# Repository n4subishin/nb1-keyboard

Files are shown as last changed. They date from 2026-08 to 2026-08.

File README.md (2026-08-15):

# Nb.1

*[日本語版はこちら / Japanese version](README.ja.md)*

A 12-position programmable macropad. Every position accepts **either a Cherry MX
compatible switch or a rotary encoder** — the two share a single footprint, so
you can build it as twelve keys, twelve knobs, or any mix in between. One
firmware build covers every variant.

| | |
|---|---|
| MCU | STM32F405RGT6 (Cortex-M4F, 168 MHz, 1 MB Flash, 192 KB RAM) |
| Matrix | 3 rows × 4 columns, COL2ROW |
| Encoders | Up to 12, wired directly to GPIO |
| Connection | USB Type-C, USB 2.0 Full Speed |
| Firmware | QMK Firmware (ChibiOS) |
| Configurator | Remap / VIA |

---

## Changing the keymap

No programming required — everything happens in the browser.

1. Open https://remap-keys.app/ in **Chrome or Edge**
   (Firefox and Safari do not implement WebHID and will not connect)
2. Choose **Customize your keyboard** and connect Nb.1
3. Drag and drop keycodes onto the positions you want to change
4. Press **flash**

Click a knob to set its clockwise and counter-clockwise actions separately.

Until Nb.1 is listed in the Remap catalog, load
[`Nb1_remap_definition.json`](Nb1_remap_definition.json) into Remap first.

---

## Building the firmware

You need a working QMK environment. See the
[QMK setup guide](https://docs.qmk.fm/newbs_getting_started) if you don't have one.

```sh
git clone https://github.com/qmk/qmk_firmware.git
cd qmk_firmware
qmk setup

# Drop this repository's keyboard directory into the QMK tree
cp -r /path/to/nb1-keyboard/keyboards/nb1 keyboards/

qmk compile -kb nb1 -km via
```

Two keymaps are provided. `default` is plain QMK; `via` adds Remap/VIA support
and is what ships on the board.

### Clock configuration

Y1 is a **16 MHz** crystal. QMK's `GENERIC_STM32_F405XG` board assumes 12 MHz,
so `board.h` and `mcuconf.h` override it:

```
PFD 2 MHz -> VCO 336 MHz -> SYSCLK 168 MHz, USB 48 MHz
```

**Deleting those two files breaks USB entirely** — the USB clock would land at
64 MHz instead of the required 48 MHz, and the core would run at 224 MHz, well
past its 168 MHz limit.

### EEPROM persistence

The STM32F405 has no real EEPROM, and QMK's flash emulation does not cover this
part by default, so it would silently fall back to a RAM-backed fake EEPROM and
lose every remap on unplug. `keymaps/via/rules.mk` selects the wear-leveling
driver explicitly to prevent that. Do not remove those lines.

---

## Flashing

Two ways into the bootloader:

**Keycode** — hold position 12 (bottom right) to reach layer 1, then press
position 1. That is `QK_BOOT` in the shipped keymap.

**BOOT0 button** — unplug USB, hold the BOOT0 button on the PCB, plug USB back
in. This works even when the firmware does not boot at all.

```sh
qmk flash -kb nb1 -km via
```

---

## Hardware

| | |
|---|---|
| PCB | 96.72 × 95.00 mm, 2 layer |
| Key pitch | 19.2 mm |
| Switches | Cherry MX compatible, Kailh hotswap sockets |
| Encoders | Alps EC12E2440301 (24 detent / 24 pulse, no push switch) |
| Crystal | 16 MHz, CL = 20 pF, HC-49/S |

Full details in [`docs/SPECIFICATION.md`](docs/SPECIFICATION.md).

### Known limitations

- **No SWD header.** Debugging requires soldering directly to MCU pins 46 and 49.
- **No reset button.** Can be retrofitted by adding a tactile switch in parallel
  with C8.
- **Matrix rows pass through the J16–J17 cable.** If that cable is disconnected,
  no key responds at all while the encoders keep working. This is the first
  thing to check when keys go dead.
- **The encoders have no push switch,** so a position fitted with an encoder
  responds to rotation only.

### JTAG pins

PA15 (JTDI), PB3 (JTDO) and PB4 (NJTRST) are used for the indicator LED and for
matrix row 3 / column 1. The board is SWD-only by design; a JTAG probe will not
work.

---

## License

Based on QMK Firmware, so this project is **GPL v2**. See [`LICENSE`](LICENSE).

USB VID `0x1209` is allocated by [pid.codes](https://pid.codes/) for open source
hardware. Projects using it must be released under a recognised open source
license, which this repository satisfies.

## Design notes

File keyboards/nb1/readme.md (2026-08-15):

# original_keyboard

A 12-position programmable input device built around an STM32F405RGT6.
Every position takes either a Cherry MX compatible switch (on a Kailh hotswap
socket) or a rotary encoder — the two share a single footprint, so the build
can be all keys, all encoders, or any mix. One firmware covers every variant.

* Keyboard maintainer: you
* Hardware supported: original_keyboard rev 1.0
* Hardware availability: self-made

## Layout

```
       col1   col2   col3   col4
 row1 [  1 ] [  2 ] [  3 ] [  4 ]
 row2 [  5 ] [  6 ] [  7 ] [  8 ]
 row3 [  9 ] [ 10 ] [ 11 ] [ 12 ]
```

Matrix position `[row, col]` and encoder index share the same physical spot:
encoder index = `row * 4 + col`.

## Building

```sh
qmk compile -kb original_keyboard -km default
```

## Flashing

```sh
qmk flash -kb original_keyboard -km default
```

Two ways to enter the bootloader:

* **Keycode** — hold position 9, press position 1 (`QK_BOOT` on the FN layer)
* **Hardware** — hold the BOOT0 button while plugging in USB

## Clock configuration

Y1 is a 16 MHz crystal (HUSG-16.000-20, CL = 20 pF). `board.h` and `mcuconf.h`
override the generic F405 board defaults:

```
PFD 2 MHz -> VCO 336 MHz -> SYSCLK 168 MHz, USB 48 MHz
```

Check `platforms/chibios/boards/GENERIC_STM32_F405XG/configs/` first — if the
defaults already match, delete both files.

## Notes

* PA15, PB3 and PB4 are JTAG pins at reset (JTDI / JTDO / NJTRST) and are used
  here for the indicator LED, matrix row 3 and matrix column 1. SWD-only debug
  is required; a JTAG probe will not work.
* The three matrix rows run through the J16 → cable → J17 jumper. If no key
  responds but the encoders do, check that cable first.

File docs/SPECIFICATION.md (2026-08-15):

# Nb.1 製品仕様書

Rev. 1.0 / 2026-08-06
KiCad 回路図 (`nb1.kicad_sch`) および基板 (`nb1.kicad_pcb`) より作成

---

## 1. 製品概要

12ポジションのプログラマブル入力デバイス。各ポジションは **Cherry MX 互換スイッチ**
または **ロータリーエンコーダ** のどちらかを選んで実装できる共用フットプリントを
採用しており、用途に応じて構成を変更できる。

USB Type-C 接続の有線デバイス。ファームウェアは QMK ベースで、
キーマップ・エンコーダ機能ともにユーザーが再定義可能。

| 項目 | 内容 |
|---|---|
| 型式 | Nb.1 |
| 入力ポジション数 | 12(3行 × 4列) |
| 各ポジションの選択肢 | Cherry MX 互換スイッチ / ロータリーエンコーダ |
| 接続 | USB 2.0 Full Speed (Type-C) |
| 電源 | USB バスパワー |
| ファームウェア | QMK Firmware (ChibiOS) |

---

## 2. 電気的仕様

### 2.1 マイクロコントローラ

| 項目 | 仕様 |
|---|---|
| 型番 | STM32F405RGT6 (U1) |
| コア | ARM Cortex-M4F @ 168 MHz |
| Flash / RAM | 1 MB / 192 KB |
| パッケージ | LQFP-64 |
| 動作電圧 | 3.3 V |

### 2.2 クロック

| 項目 | 仕様 |
|---|---|
| 発振子 (Y1) | HUSG-16.000-20、16 MHz、HC-49/S |
| 負荷容量 | CL = 20 pF(C9 / C10 = 30 pF) |
| 周波数許容差 | ±30 ppm |
| 周波数温度特性 | ±30 ppm |
| 直列抵抗 (R5) | 0 Ω |
| SYSCLK | 168 MHz(PLLM=8 / PLLN=168 / PLLP=2) |
| USB クロック | 48 MHz(PLLQ=7) |

### 2.3 電源

| 項目 | 仕様 |
|---|---|
| 入力 | USB VBUS 5 V |
| レギュレータ (U2) | M78AR033-0.5(R-78E3.3-0.5 互換) |
| 出力 | 3.3 V / 0.5 A |
| VDDA フィルタ | FB1(BLM18SP601SN1 相当)+ C12 (1 µF) / C13 (100 nF) |
| デカップリング | C3〜C7 |
| VCAP | C1 / C2(2.2 µF) |

### 2.4 USB

| 項目 | 仕様 |
|---|---|
| コネクタ (J1) | USB Type-C レセプタクル 16P(5077CR-16-SMC2-BK-TR) |
| 規格 | USB 2.0 Full Speed (12 Mbps) |
| D+ / D− | PA12 / PA11、直列 22 Ω (R3 / R4) |
| CC1 / CC2 | 5.1 kΩ プルダウン (R1 / R2) — UFP(デバイス)構成 |
| VID / PID | 0xFEED / 0x0001(出荷時、変更可) |

### 2.5 インジケータ LED

| 項目 | 仕様 |
|---|---|
| 素子 (D13) | 赤色 0603、Vf 1.8〜2.4 V、300 mcd @ 20 mA |
| 制御ピン | PA15 |
| 極性 | アノード → PA15、カソード → R6 → GND |
| 論理 | アクティブ HIGH |
| 電流制限 (R6) | 1 kΩ(実効電流 約 0.85〜1.45 mA) |

### 2.6 マトリクス

| 項目 | 仕様 |
|---|---|
| 構成 | 3行 × 4列 = 12キー |
| 行 (ROW) | PB1 / PB0 / PB3 |
| 列 (COL) | PB4 / PB5 / PB6 / PB7 |
| ダイオード | D1〜D12、SOD-123 |
| ダイオード方向 | COL2ROW(アノードが列側) |
| 行の経路 | MCU → J16 →(ケーブル)→ J17 → スイッチ |

### 2.7 ロータリーエンコーダ

12基すべてが MCU の GPIO に直結。マトリクスを介さない。

| ポジション | 行,列 | A相 | B相 | エンコーダ番号 |
|---|---|---|---|---|
| SW13 | 0,0 | PC9 | PC8 | 0 |
| SW16 | 0,1 | PA7 | PA6 | 1 |
| SW19 | 0,2 | PC13 | PC12 | 2 |
| SW22 | 0,3 | PC4 | PC5 | 3 |
| SW14 | 1,0 | PC1 | PC0 | 4 |
| SW17 | 1,1 | PC6 | PC7 | 5 |
| SW20 | 1,2 | PC15 | PC14 | 6 |
| SW23 | 1,3 | PA3 | PA2 | 7 |
| SW15 | 2,0 | PB8 | PB9 | 8 |
| SW18 | 2,1 | PC11 | PC10 | 9 |
| SW21 | 2,2 | PA5 | PA4 | 10 |
| SW24 | 2,3 | PA1 | PA0 | 11 |

共通端子 (C) は GND。内部プルアップを使用。

### 2.8 ブートローダ / デバッグ

| 項目 | 仕様 |
|---|---|
| BOOT0 | プッシュスイッチ (botton_1) で 3.3 V、R7 (10 kΩ) で GND |
| BOOT1 (PB2) | R8 (10 kΩ) で GND 固定 |
| NRST | C8 (100 nF) → GND |
| 書き込み | USB DFU(内蔵 ROM ブートローダ) |
| デバッグ | SWD (PA13 / PA14) — **基板上に端子未実装** |

---

## 3. 機構仕様

| 項目 | 仕様 |
|---|---|
| 基板外形 | 96.72 × 95.00 mm |
| 基板構成 | 両面 |
| キーピッチ | X 19.2 mm / Y 19.1 mm |
| 配列 | 3行 × 4列 グリッド |
| 取付穴 | 4箇所(MountingHole × 4) |

### 3.1 共用フットプリント寸法

各ポジションの詳細(座標はポジション中心を原点)。

**非メッキ穴(NPTH)**

| 位置 | 寸法 | 用途 |
|---|---|---|
| (0, 0) | φ4.00 mm | MX センターポスト |
| (±5.08, 0) | φ1.75 mm | MX 位置決めポスト |
| (−3.81, −2.54) | φ3.05 mm | MX スイッチピン逃げ |
| (2.54, −5.08) | φ3.05 mm | MX スイッチピン逃げ |
| (0.02, 5.00) | 長穴 11.0 × 2.6 mm | エンコーダ本体逃げ |

**裏面 SMD パッド(すべて B.Cu)**

| パッド | 位置 | サイズ | 用途 |
|---|---|---|---|
| 1 | (−7.08, −2.54) | 2.55 × 2.50 mm | Kailh ホットスワップソケット |
| 2 | (5.84, −5.08) | 2.55 × 2.50 mm | Kailh ホットスワップソケット |
| A | (−2.56, 2.95) | 1.10 × 1.10 mm | エンコーダ A相 |
| C | (2.54, 2.95) | 1.10 × 1.10 mm | エンコーダ 共通 |
| B | (−0.01, 7.05) | 1.10 × 1.10 mm | エンコーダ B相 |

### 3.2 ★ 未確定事項:エンコーダの適合

**エンコーダの型番が未確定です。発注・実装の前に必ず照合してください。**

判明している事実:

- A / B / C はすべて **1.1 mm 角の SMD パッド**(基板裏面 B.Cu)
- A-C 間 5.10 mm、B は A-C ラインから 4.10 mm オフセット、B は中央 (x≈0)
- 本体逃げは 11.0 × 2.6 mm の長穴
- スルーホール型の EC11 / EC12E とは**適合しません**

MX スイッチのボディ(14 × 14 mm、中心から ±7 mm)は A / B / C パッドの
位置と重なるため、**同一ポジションに MX スイッチとエンコーダを
同時実装することはできません。** 各ポジションはどちらか一方を選択します。

---

## 4. 構成の自由度

同一のファームウェアで、以下のいずれの構成にも対応します。
未実装のポジションは自動的に無効になります(エンコーダピンは内部プルアップ
により安定、マトリクス位置は反応しない)。

| 構成例 | MX スイッチ | エンコーダ | 用途 |
|---|---|---|---|
| フルキー | 12 | 0 | マクロパッド |
| フルエンコーダ | 0 | 12 | ミキサー / コントロールサーフェス |
| ハイブリッド A | 8 | 4 | 汎用(上段エンコーダ) |
| ハイブリッド B | 6 | 6 | DAW / 動画編集 |

---

## 5. 既知の制限事項

| # | 内容 | 影響 | 対策 |
|---|---|---|---|
| 1 | SWD 端子が未実装 | デバッガ接続不可 | MCU ピン 46 / 49 に直接配線 |
| 2 | リセットボタンなし | DFU 進入に USB 抜き差しが必要 | C8 に並列でタクトスイッチを追加 |
| 3 | 行配線が J16-J17 ケーブル経由 | ケーブル断でキー全滅 | 次回改版で基板上直結 |
| 4 | PA9 / PA10 が未接続 | ROM ブートローダの誤検出可能性 | 10 kΩ プルダウン追加 |
| 5 | フットプリントに MP パッドなし | KiCad DRC エラー | 次回改版で整合 |
| 6 | ネットラベルの番号ずれ | 可読性のみ(電気的問題なし) | 次回改版でリネーム |
| 7 | エンコーダ型番未確定 | 実装可否が未検証 | 3.2 節参照 |

### 5.1 JTAG ピンの制約

以下の3ピンは STM32F4 のリセット直後に JTAG 機能に割り当てられます。

| ピン | JTAG 機能 | 本製品での用途 |
|---|---|---|
| PA15 | JTDI | インジケータ LED |
| PB3 | JTDO | 行 IN_3 |
| PB4 | NJTRST | 列 OUT_1 |

SWD (PA13 / PA14) のみで運用するため動作に支障はありませんが、
**JTAG デバッガは使用できません。**

### 5.2 バックアップドメインピン

PC13 / PC14 / PC15 は出力駆動能力が 3 mA / 2 MHz に制限されます。
本製品ではエンコーダ入力にのみ使用するため影響ありません。

---

## 6. 未使用リソース

将来の拡張に利用可能な GPIO:

| ピン | 代表的な代替機能 | 想定用途 |
|---|---|---|
| PB10 / PB11 | I2C2_SCL / SDA | OLED ディスプレイ |
| PA8 | TIM1_CH1 | WS2812 RGB |
| PA9 / PA10 | USART1_TX / RX | シリアル、ブートローダ救済 |
| PC2 / PC3 | ADC | アナログ入力 |
| PB12〜PB15 | SPI2 | 外部メモリ等 |
| PD2 | — | 汎用 |

Flash 使用量は QMK 標準構成で 1 MB 中の一部のみ。RAM 192 KB。
機能拡張の余地は十分にあります。

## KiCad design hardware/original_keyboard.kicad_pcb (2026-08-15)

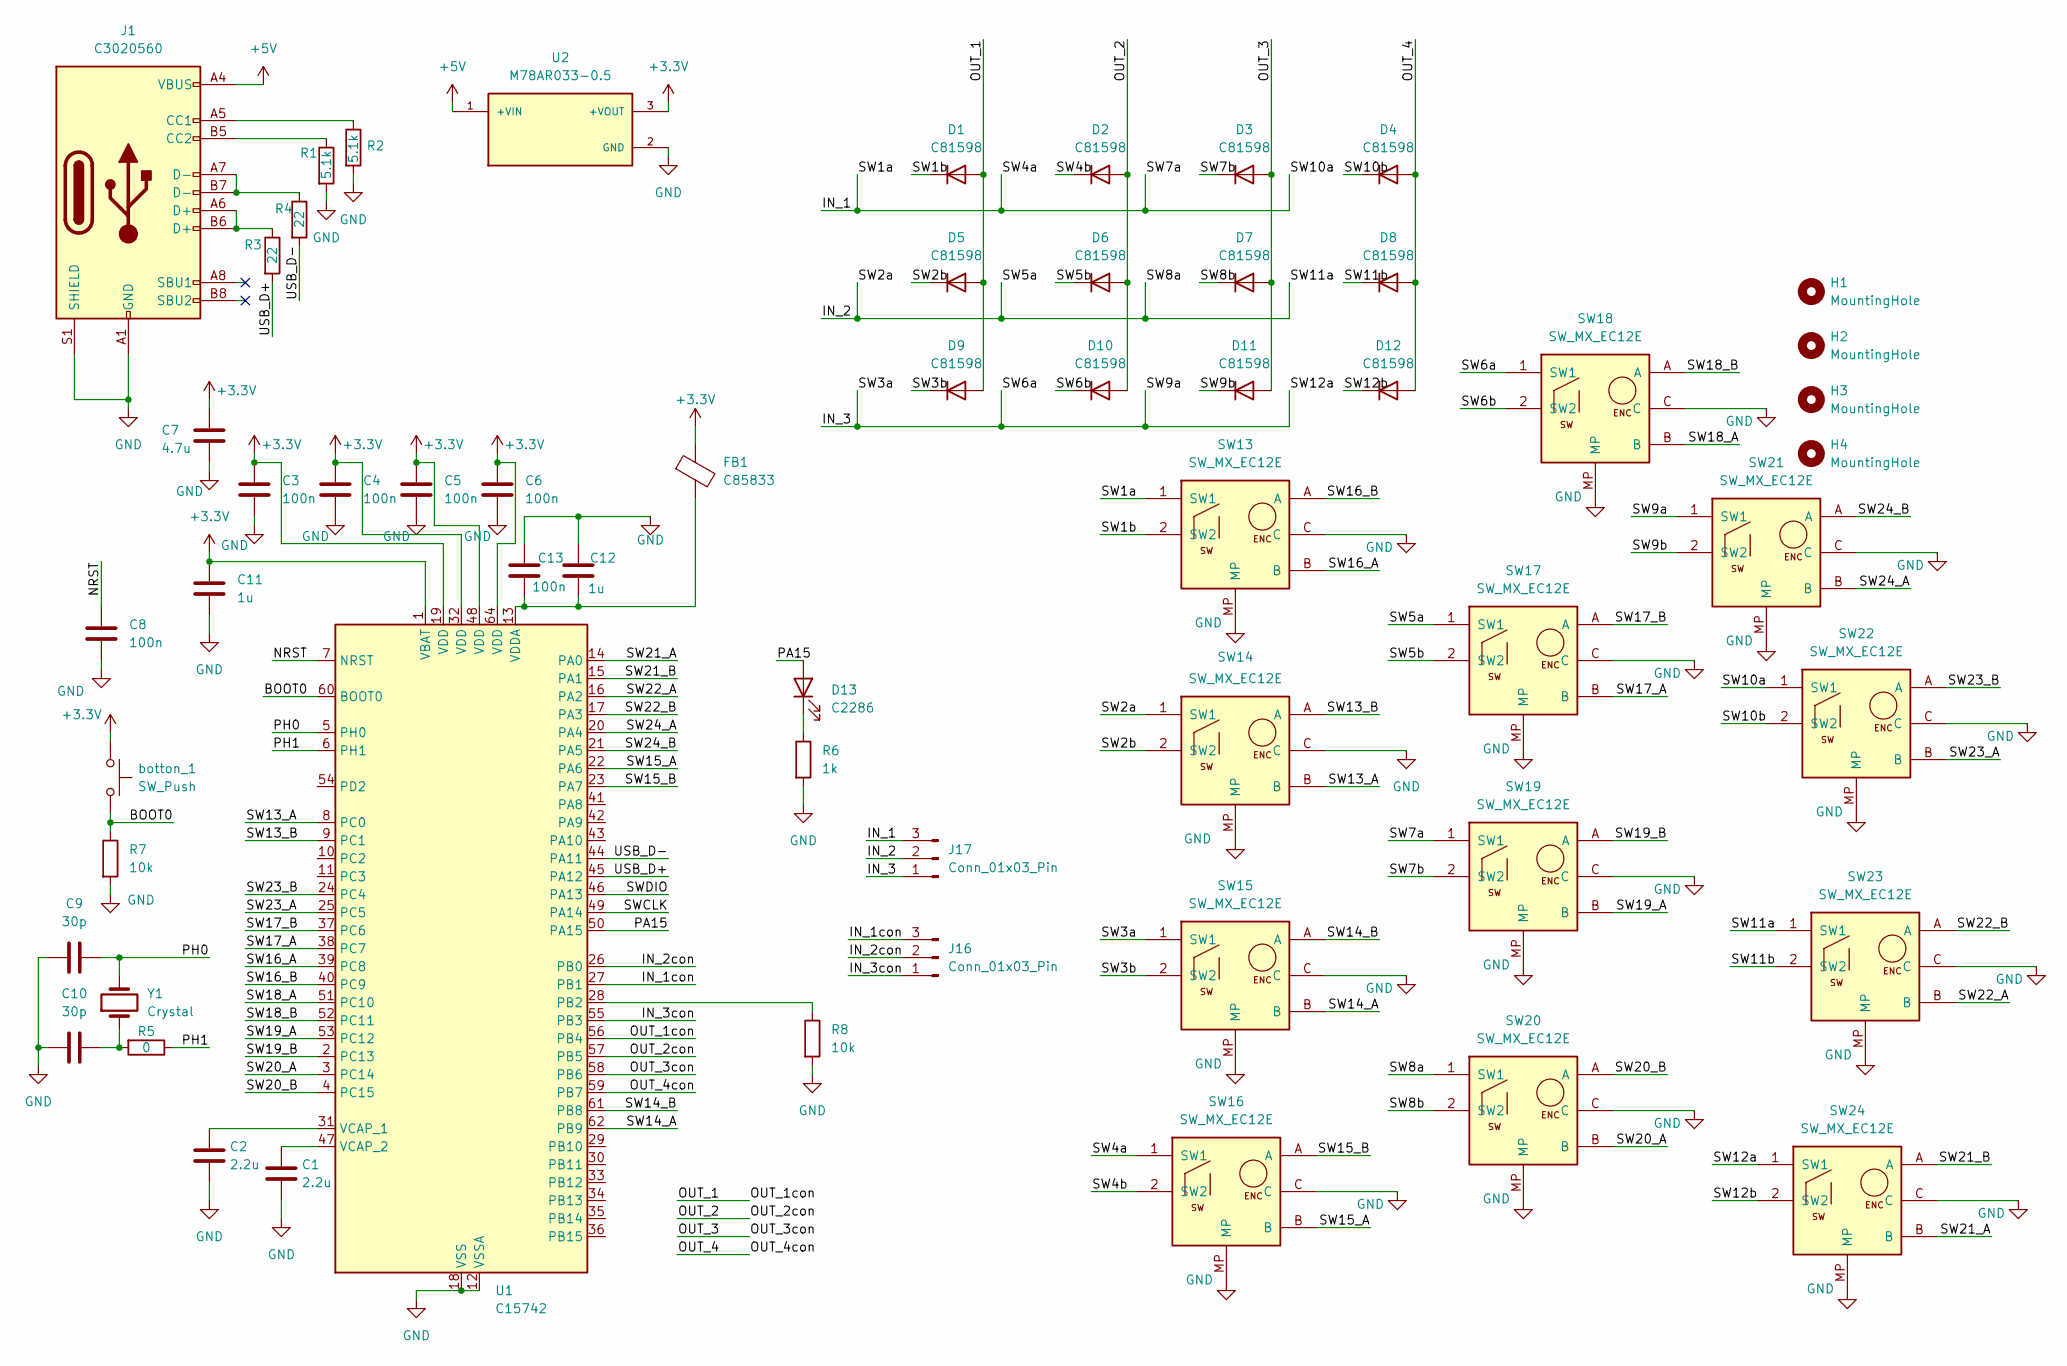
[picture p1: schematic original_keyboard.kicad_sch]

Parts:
C1, C2: 2.2u; C_0603_1608Metric
C3, C4, C5, C6, C8, C13: 100n; C_0603_1608Metric
C7: 4.7u; C_0603_1608Metric
C9, C10: 30p; C_0603_1608Metric
C11, C12: 1u; C_0603_1608Metric
D1, D2, D3, D4, D5, D6, D7, D8, D9, D10, D11, D12: C81598; D_SOD-123
D13: C2286; LED_0603_1608Metric
FB1: C85833; C_0603_1608Metric
H1, H2, H3, H4: MountingHole; MountingHole_3.2mm_M3
J1: C3020560; USB_C_Receptacle_GCT_USB4105-xx-A_16P_TopMnt_Horizontal
J16, J17: Conn_01x03_Pin; PinHeader_1x03_P2.54mm_Vertical
R1, R2: 5.1k; R_0603_1608Metric
R3, R4: 22; R_0603_1608Metric
R5: 0; R_0603_1608Metric
R6: 1k; R_0603_1608Metric
R7, R8: 10k; R_0603_1608Metric
SW13, SW14, SW15, SW16, SW17, SW18, SW19, SW20, SW21, SW22, SW23, SW24: SW_MX_EC12E; original1
U1: C15742; LQFP-64_10x10mm_P0.5mm
U2: M78AR033-0.5; PARTREV 4
Y1: Crystal; Crystal_HC49-U_Vertical
botton_1: SW_Push; SW_PUSH_6mm

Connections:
+3.3V: C3.1, C4.1, C5.1, C6.1, C7.1, C11.1, FB1.1, U1.1 (VBAT), U1.19 (VDD), U1.32 (VDD), U1.48 (VDD), U1.64 (VDD), U2.3 (+VOUT), botton_1.1
+5V: J1.A4 (VBUS), J1.A9 (VBUS), J1.B4 (VBUS), J1.B9 (VBUS), U2.1 (+VIN)
/BOOT0: R7.1, U1.60 (BOOT0), botton_1.2
/IN_1: J17.3, SW13.1 (SW1), SW16.1 (SW1), SW19.1 (SW1), SW22.1 (SW1)
/IN_1con: J16.3, U1.27 (PB1)
/IN_2: J17.2, SW14.1 (SW1), SW17.1 (SW1), SW20.1 (SW1), SW23.1 (SW1)
/IN_2con: J16.2, U1.26 (PB0)
/IN_3: J17.1, SW15.1 (SW1), SW18.1 (SW1), SW21.1 (SW1), SW24.1 (SW1)
/IN_3con: J16.1, U1.55 (PB3)
/NRST: C8.1, U1.7 (NRST)
/OUT_1: D1.2 (A), D5.2 (A), D9.2 (A), U1.56 (PB4)
/OUT_2: D2.2 (A), D6.2 (A), D10.2 (A), U1.57 (PB5)
/OUT_3: D3.2 (A), D7.2 (A), D11.2 (A), U1.58 (PB6)
/OUT_4: D4.2 (A), D8.2 (A), D12.2 (A), U1.59 (PB7)
/PA15: D13.2 (A), U1.50 (PA15)
/PH0: C9.1, U1.5 (PH0), Y1.2
/PH1: R5.1, U1.6 (PH1)
/SW1b: D1.1 (K), SW13.2 (SW2)
/SW2b: D5.1 (K), SW14.2 (SW2)
/SW3b: D9.1 (K), SW15.2 (SW2)
/SW4b: D2.1 (K), SW16.2 (SW2)
/SW5b: D6.1 (K), SW17.2 (SW2)
/SW6b: D10.1 (K), SW18.2 (SW2)
/SW7b: D3.1 (K), SW19.2 (SW2)
/SW8b: D7.1 (K), SW20.2 (SW2)
/SW9b: D11.1 (K), SW21.2 (SW2)
/SW10b: D4.1 (K), SW22.2 (SW2)
/SW11b: D8.1 (K), SW23.2 (SW2)
/SW12b: D12.1 (K), SW24.2 (SW2)
/SW13_A: SW14.B, U1.8 (PC0)
/SW13_B: SW14.A, U1.9 (PC1)
/SW14_A: SW15.B, U1.62 (PB9)
/SW14_B: SW15.A, U1.61 (PB8)
/SW15_A: SW16.B, U1.22 (PA6)
/SW15_B: SW16.A, U1.23 (PA7)
/SW16_A: SW13.B, U1.39 (PC8)
/SW16_B: SW13.A, U1.40 (PC9)
/SW17_A: SW17.B, U1.38 (PC7)
/SW17_B: SW17.A, U1.37 (PC6)
/SW18_A: SW18.B, U1.51 (PC10)
/SW18_B: SW18.A, U1.52 (PC11)
/SW19_A: SW19.B, U1.53 (PC12)
/SW19_B: SW19.A, U1.2 (PC13)
/SW20_A: SW20.B, U1.3 (PC14)
/SW20_B: SW20.A, U1.4 (PC15)
/SW21_A: SW24.B, U1.14 (PA0)
/SW21_B: SW24.A, U1.15 (PA1)
/SW22_A: SW23.B, U1.16 (PA2)
/SW22_B: SW23.A, U1.17 (PA3)
/SW23_A: SW22.B, U1.25 (PC5)
/SW23_B: SW22.A, U1.24 (PC4)
/SW24_A: SW21.B, U1.20 (PA4)
/SW24_B: SW21.A, U1.21 (PA5)
/SWCLK: U1.49 (PA14)
/SWDIO: U1.46 (PA13)
/USB_D+: R3.2, U1.45 (PA12)
/USB_D-: R4.2, U1.44 (PA11)
GND: C1.2, C2.2, C3.2, C4.2, C5.2, C6.2, C7.2, C8.2, C9.2, C10.2, C11.2, C12.1, C13.1, J1.A1 (GND), J1.A12 (GND), J1.B1 (GND), J1.B12 (GND), J1.S1 (SHIELD), R1.2, R2.2, R6.2, R7.2, R8.2, SW13.C, SW13.MP, SW14.C, SW14.MP, SW15.C, SW15.MP, SW16.C, SW16.MP, SW17.C, SW17.MP, SW18.C, SW18.MP, SW19.C, SW19.MP, SW20.C, SW20.MP, SW21.C, SW21.MP, SW22.C, SW22.MP, SW23.C, SW23.MP, SW24.C, SW24.MP, U1.12 (VSSA), U1.18 (VSS), U1.63 (VSS), U2.2 (GND)
unnamed: C10.1, R5.2, Y1.1
unnamed: D13.1 (K), R6.1
unnamed: J1.A5 (CC1), R2.1
unnamed: J1.B5 (CC2), R1.1
unnamed: J1.A6 (D+), J1.B6 (D+), R3.1
unnamed: J1.A7 (D-), J1.B7 (D-), R4.1
unnamed: R8.1, U1.28 (PB2)
unnamed: C2.1, U1.31 (VCAP_1)
unnamed: C1.1, U1.47 (VCAP_2)
unnamed: C12.2, C13.2, FB1.2, U1.13 (VDDA)

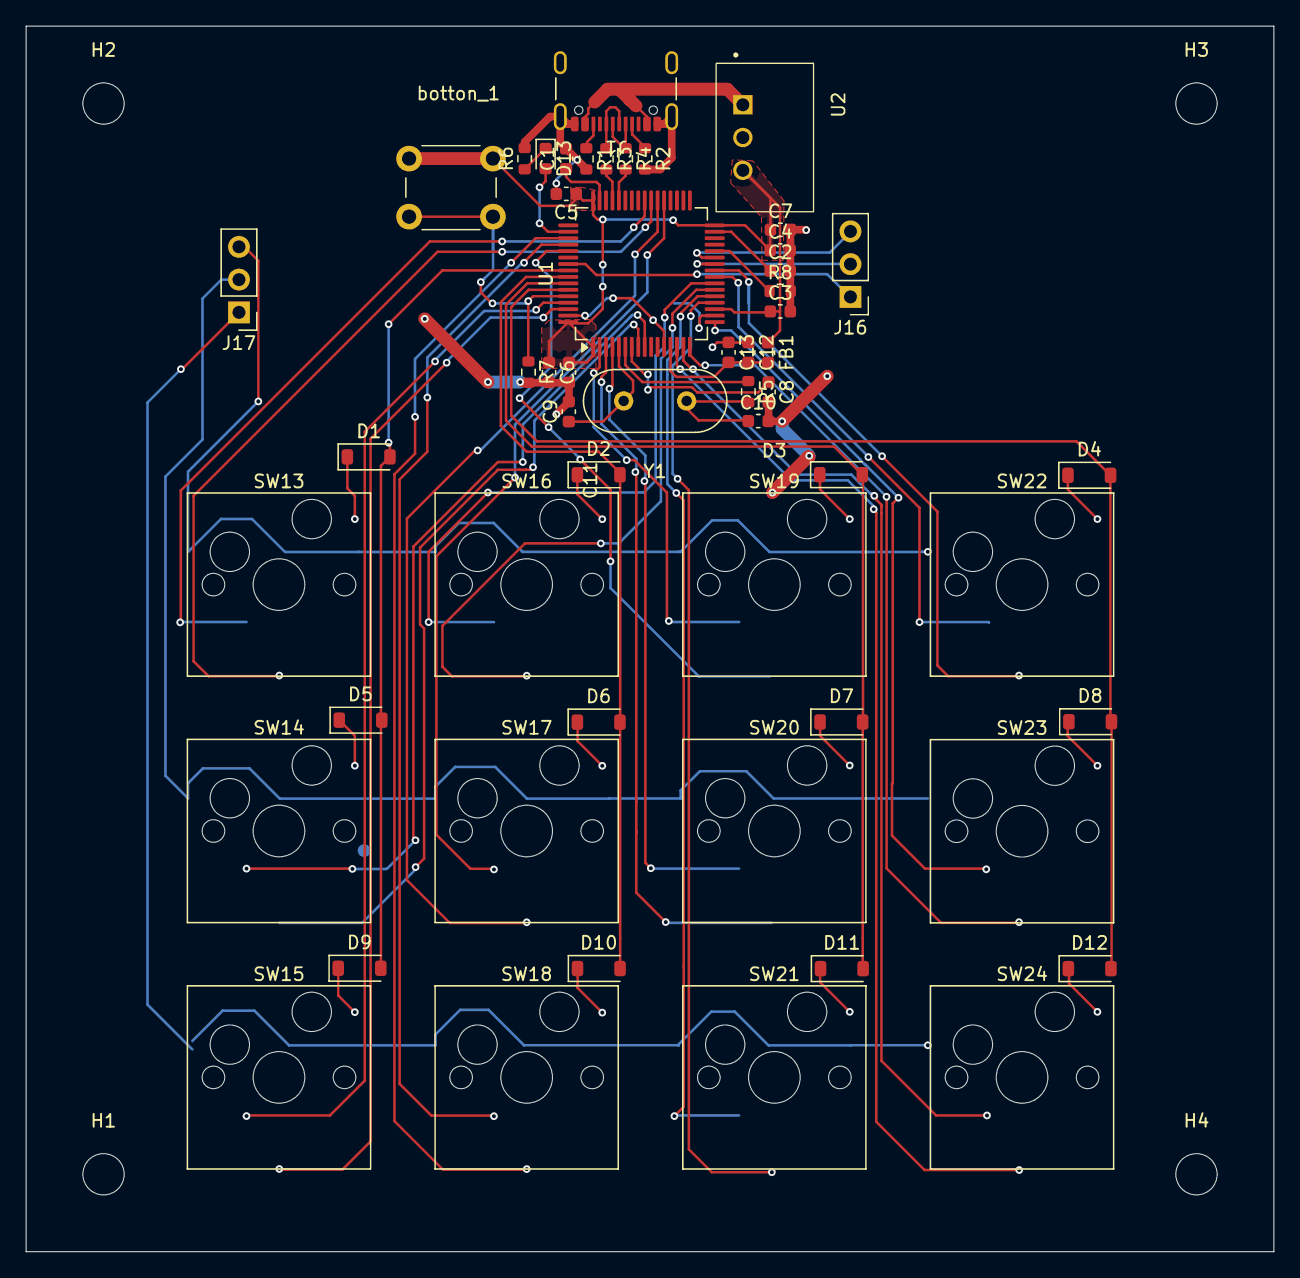
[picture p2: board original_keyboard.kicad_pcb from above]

Board: 2 copper layers, 96.7 x 95.0 mm, 58 parts (0 on the bottom side), 66 nets.

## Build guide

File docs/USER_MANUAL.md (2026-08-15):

# Nb.1 取扱説明書

Rev. 1.0 / 2026-08-06

---

## 1. はじめに

本製品は12ポジションのプログラマブル入力デバイスです。
各ポジションには **Cherry MX 互換スイッチ**または**ロータリーエンコーダ**の
どちらかが実装されています。

配列は3行 × 4列。左上を「1番」として、以下のように数えます。

```
       列1    列2    列3    列4
行1  [  1 ] [  2 ] [  3 ] [  4 ]
行2  [  5 ] [  6 ] [  7 ] [  8 ]
行3  [  9 ] [ 10 ] [ 11 ] [ 12 ]
```

---

## 2. 接続

USB Type-C ケーブルで PC に接続するだけです。ドライバのインストールは
不要で、標準的な USB キーボードとして認識されます。

Windows / macOS / Linux / ChromeOS に対応します。

**注意:** ケーブルは必ず**データ通信対応**のものを使ってください。
充電専用ケーブルでは認識されません。

---

## 3. 出荷時の割り当て

### 3.1 レイヤー構成

本製品には2つのレイヤーがあります。

| レイヤー | 名称 | 呼び出し方 |
|---|---|---|
| 0 | BASE | 通常状態 |
| 1 | FN | ポジション9を押している間 |

### 3.2 BASE レイヤー(通常時)

**押したとき**

| ポジション | 機能 |
|---|---|
| 1 | ミュート切り替え |
| 2 | 前のトラック |
| 3 | 再生 / 一時停止 |
| 4 | 次のトラック |
| 5 | テンキー 7 |
| 6 | テンキー 8 |
| 7 | テンキー 9 |
| 8 | ÷ |
| 9 | **FN レイヤー(押している間)** |
| 10 | テンキー 0 |
| 11 | . |
| 12 | Enter |

**回したとき(エンコーダ実装ポジション)**

| ポジション | 左回り | 右回り |
|---|---|---|
| 1 | 音量ダウン | 音量アップ |
| 2 | 前のトラック | 次のトラック |
| 3 | Page Down | Page Up |
| 4 | ← | → |
| 5 | ホイール下 | ホイール上 |
| 6 | ↑ | ↓ |
| 7 | マウス左 | マウス右 |
| 8 | Shift+Tab | Tab |
| 9 | − | = |
| 10 | [ | ] |
| 11 | , | . |
| 12 | 画面輝度ダウン | 画面輝度アップ |

### 3.3 FN レイヤー(ポジション9を押しながら)

| ポジション | 機能 |
|---|---|
| 1 | **書き込みモードに入る** |
| 2〜4 | F13 / F14 / F15 |
| 5〜8 | F16 / F17 / F18 / F19 |
| 10〜12 | F20 / F21 / F22 |

F13〜F22 は通常のキーボードには無いキーなので、
アプリのショートカット割り当てに便利です。

---

## 4. インジケータ LED

基板上の赤色 LED は、出荷時は **Num Lock 連動**です。
Num Lock がオンのときに点灯します。

レイヤー表示など、他の用途に変更することもできます(6章参照)。

---

## 5. 書き込みモード(ファームウェア更新)

ファームウェアを書き換えるには、書き込みモード(DFU モード)に入ります。
方法は2つあります。

### 方法1:キー操作(通常はこちら)

**ポジション9を押しながら、ポジション1を押す。**

即座に書き込みモードに入り、PC からは「STM32 BOOTLOADER」として
認識されます。キーボードとしては一時的に反応しなくなります。

### 方法2:BOOT0 ボタン(ファームが壊れたとき)

1. USB ケーブルを抜く
2. 基板上の **BOOT0 ボタンを押したまま**
3. USB ケーブルを挿す
4. ボタンを離す

ファームウェアが起動しない状態でも、この方法なら必ず書き込みモードに入れます。

### 書き込みコマンド

```bash
qmk flash -kb nb1 -km default
```

または

```bash
dfu-util -a 0 -d 0483:df11 -s 0x08000000:leave -D nb1_default.bin
```

書き込みが終わると自動的に再起動し、通常のキーボードに戻ります。

---

## 6. カスタマイズ

### 6.1 準備

QMK の開発環境を用意し、本製品のファイル一式を配置します。

```
qmk_firmware/keyboards/nb1/
├── keyboard.json
├── config.h
├── board.h
├── mcuconf.h
└── keymaps/default/
    ├── keymap.c
    └── rules.mk
```

ビルドは以下のコマンドです。

```bash
qmk compile -kb nb1 -km default
```

### 6.2 キーの割り当てを変える

`keymap.c` の `keymaps` 配列を編集します。左上から右下へ、
行ごとに並んでいます。

```c
[_BASE] = LAYOUT_3x4(
    KC_MUTE, KC_MPRV, KC_MPLY, KC_MNXT,   // ポジション 1〜4
    KC_P7,   KC_P8,   KC_P9,   KC_PSLS,   // ポジション 5〜8
    MO(_FN), KC_P0,   KC_PDOT, KC_PENT    // ポジション 9〜12
),
```

使えるキーコードの一覧は QMK 公式ドキュメントを参照してください。

### 6.3 エンコーダの割り当てを変える

`keymap.c` の `encoder_map` を編集します。
各行が `{ 左回り, 右回り }` です。

```c
{ KC_VOLD, KC_VOLU },  //  0  ポジション1
```

### 6.4 回転方向が逆のとき

`keyboard.json` の該当エンコーダの `pin_a` と `pin_b` を入れ替えます。

```json
{ "pin_a": "C8",  "pin_b": "C9"  }
```

### 6.5 1ノッチで2回動く / 半分しか動かないとき

`config.h` の以下の行のコメントを外して調整します。

```c
#define ENCODER_RESOLUTION 4
```

1ノッチで2回反応するなら値を大きく(4 → 8)、
半分しか反応しないなら小さく(4 → 2)します。

### 6.6 LED の動作を変える

`keymap.c` の以下の部分を書き換えます。

```c
bool led_update_user(led_t led_state) {
    writePin(INDICATOR_LED, led_state.num_lock);
    return false;
}
```

レイヤー表示にしたい場合は、`led_update_user` の中身を
`return false;` だけにして、`layer_state_set_user` を使います
(`keymap.c` にコメントで例を記載しています)。

---

## 7. トラブルシューティング

### PC に認識されない

まず**データ通信対応のケーブル**か確認してください。充電専用ケーブルが
原因のことが最も多いです。

それでも認識されない場合、BOOT0 ボタンを押しながら接続して
「STM32 BOOTLOADER」が見えるか確認します。

- **見える** → ファームウェアの問題。書き込み直してください
- **見えない** → ハードウェアの問題。組み立て手順書を参照してください

### キーが1つも反応しない(エンコーダは動く)

**J16 と J17 を繋ぐケーブルを確認してください。**
マトリクスの行3本すべてがこのケーブルを通っているため、
外れていると全キーが無反応になります。

エンコーダは MCU 直結なので、ケーブルが無くても動作します。
この症状が出たら、ほぼ確実にケーブルが原因です。

### キーの位置がずれている

J16-J17 のケーブルが逆向き(1-3、3-1)に繋がっています。
ケーブルを正しく繋ぎ直してください(1-1、2-2、3-3 のストレート)。

### 特定のキーだけ反応しない

そのポジションの以下を確認してください。

- Kailh ホットスワップソケットのはんだ付け
- スイッチのピンが曲がっていないか
- 対応するダイオードの向きとはんだ付け

### エンコーダが反応しない / 飛ぶ

- A / B / C パッドのはんだ付けを確認
- 反応が飛ぶ場合は `ENCODER_RESOLUTION` を調整(6.5節)
- 逆回転する場合は `pin_a` / `pin_b` を入れ替え(6.4節)

### 書き込み後に動かなくなった

BOOT0 ボタンを押しながら USB を挿せば、必ず書き込みモードに入れます。
正常に動いていたファームウェアを書き戻してください。

---

## 8. 取り扱い上の注意

- 動作温度範囲は 0〜50 ℃ を目安としてください
  (発振子の定格が −10〜60 ℃ です)
- 基板がむき出しの状態では、金属面の上に直接置かないでください
- USB ケーブルの抜き差しは、コネクタ部分を持って行ってください
- 分解・改造による故障は自己責任となります

---

## 9. 仕様

詳細は `SPECIFICATION.md` を参照してください。

| 項目 | 内容 |
|---|---|
| ポジション数 | 12(3 × 4) |
| 接続 | USB Type-C(USB 2.0 Full Speed) |
| 電源 | USB バスパワー |
| MCU | STM32F405RGT6 |
| 基板寸法 | 96.72 × 95.00 mm |
| キーピッチ | 19.2 mm |
| ファームウェア | QMK Firmware |

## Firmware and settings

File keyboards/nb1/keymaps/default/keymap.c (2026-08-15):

// Copyright 2026
// SPDX-License-Identifier: GPL-2.0-or-later

#include QMK_KEYBOARD_H

enum layers { _BASE = 0, _FN };

// ---------------------------------------------------------------------------
// Position numbering (matches the user manual)
//
//        col1   col2   col3   col4
//  row1 [  1 ] [  2 ] [  3 ] [  4 ]      SW13  SW16  SW19  SW22
//  row2 [  5 ] [  6 ] [  7 ] [  8 ]      SW14  SW17  SW20  SW23
//  row3 [  9 ] [ 10 ] [ 11 ] [ 12 ]      SW15  SW18  SW21  SW24
//
// Every position takes EITHER a Cherry MX switch (via a Kailh hotswap socket)
// OR a rotary encoder -- the two share one footprint and cannot coexist.
// This single firmware covers any mix: unpopulated encoders idle high on their
// internal pull-ups, and unpopulated matrix positions simply never trigger.
//
// NUM LOCK INDEPENDENCE
// KC_P0..KC_P9 and KC_PDOT change meaning when Num Lock is off (Home, arrows,
// Insert, Delete...). This board has no Num Lock key, so the user would have no
// way to fix that state. The digits below are the main-row keycodes KC_0..KC_9,
// which always send digits. Keypad OPERATORS (KC_PSLS, KC_PAST, KC_PMNS,
// KC_PPLS, KC_PENT) are not affected by Num Lock and are safe to use.
// ---------------------------------------------------------------------------

const uint16_t PROGMEM keymaps[][MATRIX_ROWS][MATRIX_COLS] = {
    // 7 8 9 Backspace / 4 5 6 Enter / 1 2 3 (tap 0, hold FN)
    [_BASE] = LAYOUT_3x4(
        KC_7,    KC_8,    KC_9,    KC_BSPC,
        KC_4,    KC_5,    KC_6,    KC_PENT,
        KC_1,    KC_2,    KC_3,    LT(_FN, KC_0)
    ),

    [_FN] = LAYOUT_3x4(
        KC_PSLS, KC_PAST, KC_PMNS, KC_DEL,
        KC_PPLS, KC_EQL,  KC_DOT,  KC_TAB,
        KC_COMM, KC_LPRN, KC_RPRN, _______
    ),
};

#ifdef ENCODER_MAP_ENABLE
// Same order as the "rotary" array in keyboard.json: { CCW, CW }
const uint16_t PROGMEM encoder_map[][NUM_ENCODERS][2] = {
    [_BASE] = {
        { KC_VOLD, KC_VOLU  },  //  0  position 1
        { KC_MPRV, KC_MNXT  },  //  1  position 2
        { KC_PGDN, KC_PGUP  },  //  2  position 3
        { KC_LEFT, KC_RGHT  },  //  3  position 4

        { MS_WHLD, MS_WHLU  },  //  4  position 5
        { KC_UP,   KC_DOWN  },  //  5  position 6
        { MS_LEFT, MS_RGHT  },  //  6  position 7
        { S(KC_TAB), KC_TAB },  //  7  position 8

        { KC_MINS, KC_EQL   },  //  8  position 9
        { KC_LBRC, KC_RBRC  },  //  9  position 10
        { KC_COMM, KC_DOT   },  // 10  position 11
        { KC_BRID, KC_BRIU  },  // 11  position 12
    },
    [_FN] = {
        { KC_VOLD, KC_VOLU },
        { KC_MPRV, KC_MNXT },
        { KC_HOME, KC_END  },
        { KC_LEFT, KC_RGHT },

        { MS_WHLD, MS_WHLU },
        { KC_UP,   KC_DOWN },
        { MS_LEFT, MS_RGHT },
        { S(KC_TAB), KC_TAB },

        { KC_MINS, KC_EQL  },
        { KC_LBRC, KC_RBRC },
        { KC_COMM, KC_DOT  },
        { KC_BRID, KC_BRIU },
    },
};
#endif

// ---------------------------------------------------------------------------
// Indicator LED on PA15
//
// Red 0603, anode to PA15, cathode through R6 (1k) to GND -> active HIGH.
// PA15 is JTDI at reset on STM32F4, so it has to be claimed as a plain GPIO
// output before use. Only SWD (PA13/PA14) is used for debug, so this is safe.
//
// Num Lock is meaningless on this board now, so the LED tracks the active
// layer instead: lit whenever the user is holding the FN layer.
// ---------------------------------------------------------------------------

#define INDICATOR_LED A15

void keyboard_post_init_user(void) {
    gpio_set_pin_output(INDICATOR_LED);
    gpio_write_pin_low(INDICATOR_LED);
}

layer_state_t layer_state_set_user(layer_state_t state) {
    gpio_write_pin(INDICATOR_LED, get_highest_layer(state) != _BASE);
    return state;
}

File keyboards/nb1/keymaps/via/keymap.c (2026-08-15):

// Copyright 2026
// SPDX-License-Identifier: GPL-2.0-or-later

#include QMK_KEYBOARD_H

// ---------------------------------------------------------------------------
// VIA / Remap keymap
//
// What is compiled here is only the FACTORY DEFAULT. Once the customer opens
// Remap and saves a change, their keymap lives in EEPROM and this file stops
// mattering. So the job here is a sensible out-of-the-box state, not a final
// design.
//
// Layer count must match DYNAMIC_KEYMAP_LAYER_COUNT (4) in config.h. Layers 2
// and 3 are left transparent for the customer to fill in.
//
//        col1   col2   col3   col4
//  row1 [  1 ] [  2 ] [  3 ] [  4 ]
//  row2 [  5 ] [  6 ] [  7 ] [  8 ]
//  row3 [  9 ] [ 10 ] [ 11 ] [ 12 ]
//
// Digits are the main-row KC_0..KC_9, never KC_P0..KC_P9: this board has no
// Num Lock key, so keypad digits would be stuck as Home/arrows/Insert whenever
// the host had Num Lock off, with no way for the customer to recover.
// ---------------------------------------------------------------------------

const uint16_t PROGMEM keymaps[][MATRIX_ROWS][MATRIX_COLS] = {
    [0] = LAYOUT_3x4(
        KC_7,    KC_8,    KC_9,    KC_BSPC,
        KC_4,    KC_5,    KC_6,    KC_PENT,
        KC_1,    KC_2,    KC_3,    LT(1, KC_0)
    ),

    [1] = LAYOUT_3x4(
        KC_PSLS, KC_PAST, KC_PMNS, KC_DEL,
        KC_PPLS, KC_EQL,  KC_DOT,  KC_TAB,
        KC_COMM, KC_LPRN, KC_RPRN, _______
    ),

    [2] = LAYOUT_3x4(
        _______, _______, _______, _______,
        _______, _______, _______, _______,
        _______, _______, _______, _______
    ),

    [3] = LAYOUT_3x4(
        _______, _______, _______, _______,
        _______, _______, _______, _______,
        _______, _______, _______, _______
    ),
};

#ifdef ENCODER_MAP_ENABLE
// Encoder index = row * 4 + col, matching the "rotary" array in keyboard.json.
// Each row is { counter-clockwise, clockwise }.
const uint16_t PROGMEM encoder_map[][NUM_ENCODERS][2] = {
    [0] = {
        { KC_VOLD, KC_VOLU  }, { KC_MPRV, KC_MNXT  },
        { KC_PGDN, KC_PGUP  }, { KC_LEFT, KC_RGHT  },
        { MS_WHLD, MS_WHLU  }, { KC_UP,   KC_DOWN  },
        { MS_LEFT, MS_RGHT  }, { S(KC_TAB), KC_TAB },
        { KC_MINS, KC_EQL   }, { KC_LBRC, KC_RBRC  },
        { KC_COMM, KC_DOT   }, { KC_BRID, KC_BRIU  },
    },
    [1] = {
        { KC_VOLD, KC_VOLU  }, { KC_MPRV, KC_MNXT  },
        { KC_HOME, KC_END   }, { KC_LEFT, KC_RGHT  },
        { MS_WHLD, MS_WHLU  }, { KC_UP,   KC_DOWN  },
        { MS_LEFT, MS_RGHT  }, { S(KC_TAB), KC_TAB },
        { KC_MINS, KC_EQL   }, { KC_LBRC, KC_RBRC  },
        { KC_COMM, KC_DOT   }, { KC_BRID, KC_BRIU  },
    },
    [2] = {
        { _______, _______ }, { _______, _______ },
        { _______, _______ }, { _______, _______ },
        { _______, _______ }, { _______, _______ },
        { _______, _______ }, { _______, _______ },
        { _______, _______ }, { _______, _______ },
        { _______, _______ }, { _______, _______ },
    },
    [3] = {
        { _______, _______ }, { _______, _______ },
        { _______, _______ }, { _______, _______ },
        { _______, _______ }, { _______, _______ },
        { _______, _______ }, { _______, _______ },
        { _______, _______ }, { _______, _______ },
        { _______, _______ }, { _______, _______ },
    },
};
#endif

// ---------------------------------------------------------------------------
// Indicator LED on PA15 -- active HIGH (anode to PA15, cathode via R6 to GND).
// PA15 is JTDI at reset on STM32F4 and must be claimed as a plain GPIO first;
// SWD-only debug makes that safe.
//
// Lit whenever any layer above the base one is active, so the customer can see
// which layer they are on regardless of how they remap the layer keys.
// ---------------------------------------------------------------------------

#define INDICATOR_LED A15

void keyboard_post_init_user(void) {
    gpio_set_pin_output(INDICATOR_LED);
    gpio_write_pin_low(INDICATOR_LED);
}

layer_state_t layer_state_set_user(layer_state_t state) {
    gpio_write_pin(INDICATOR_LED, get_highest_layer(state) != 0);
    return state;
}
